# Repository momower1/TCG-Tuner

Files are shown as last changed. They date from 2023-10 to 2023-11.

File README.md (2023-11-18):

# TCG-Tuner
TCG-Tuner is the combination of an electronic playmat with an android app that detects individual cards and plays corresponding sound effects in trading card games. Each card needs to be double sleeved and an RFID tag sticker with a unique ID is placed outside of the inner sleeve. The TCG-Tuner electronic playmat has 8 RFID scanners, one for each card zone, and detects when a card is played and notifies the TCG-Tuner android app about its card ID over bluetooth. The app then plays a corresponding sound from the app storage directory. The BLE connection requires the device address, service UUID and characteristic UUID to be configured correctly in the app preferences menu. Then, when a tag ID is received, the app will look for the \"RFID.txt\" file in the app storage directory. This file contains mappings from tag ID to sound filename separated by \"->\" in each line. TCG-Tuner will then play the sound file that is referenced by the ID. All audio files needd to be placed into the storage directory. The storage directory path can be obtained from the app preferences menu.

Example RFID.txt content:
<br>``D368B20D -> OP02-01.wav``
<br>``8320DC0F -> OP03-17.wav``

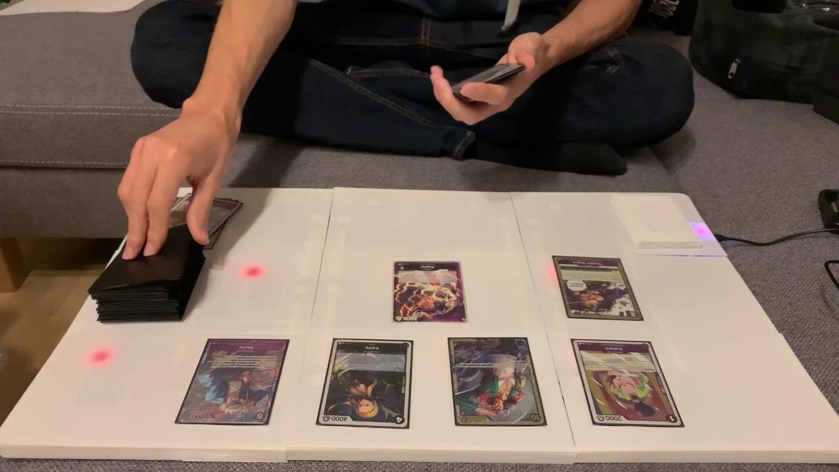
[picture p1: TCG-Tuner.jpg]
TCG-Tuner


# Hardware Setup
- Android Smartphone
- USB-Micro Power Supply
- Electronics
  - 1x ESP32-C3-MINI-1 (Development Board) https://de.aliexpress.com/item/1005004998207821.html
  - 8x RFID-RC522 Reader https://de.aliexpress.com/item/32801850680.html
  - 50x NFC Tag Sticker (NTAG215) https://www.amazon.de/dp/B0C623J1C7
  - 7x Colored Cables 24 AWG https://www.amazon.de/dp/B0B15DCC17
  - 3x Pin Header 40 Pins 2,54mm 90 Degrees https://www.ebay.de/itm/334326227743
  - 3x Pin Socket 40 Pins 2,54mm https://www.ebay.de/itm/153869572374
  - 6x Rubber Band
- 3D Printing
  - Print Settings
    - Material: PLA
    - Nozzle Size: 0.2
    - Print Temperature: 210°C
    - Bed Temperature: 60°C
    - Print Speed: 60mm/s
    - Adhesion Type: Skirt
    - Support: Off
    - Infill: 25%
  - Parts
    - 1x Bottom 1-9
    - 1x Top 1-9
    - 16x Connector
- Playmat Construction
  - 3D Print all parts
  - Bottom parts are split into 3 foldable segments consisting of 3 parts
  - The segments are connected with rubber bands, making them foldable
  - For each segment, glue the parts together using the connectors
  - Place the RFID sensors into their slots
  - Place the ESP32-C3-MINI-1 into its slot
  - Connect the pins with wires
    - For all RFID sensors
      - Solder SCK together and connect it to GPIO6 (FSPICLK)
      - Solder MOSI together and connect it to GPIO7 (FSPID)
      - Solder MISO together and connect it to GPIO2 (FSPIQ)
      - Solder RST together and connect it to GPIO10 (FSPICSO)
      - Solder GND together and connect it to GND
      - Solder 3.3V together and connect it to 3.3V
    - For each individual RFID sensor
      - Connect its SDA pin to a GPIO pin
      - E.g. One Piece TCG
        - SDA Character1 connected to GPIO0
        - SDA Character2 connected to GPIO1
        - SDA Character3 connected to GPIO3
        - SDA Character4 connected to GPIO4
        - SDA Character5 connected to GPIO5
        - SDA Event connected to GPIO9
        - SDA Leader connected to GPIO18
        - SDA Stage connected to GPIO19
  - Top parts are clipped onto the bottom parts
    - Connect the bottom segments with 3 rubber bands each and layout wires beforehand

# Software Setup
## ESP32-C3-MINI-1
- Follow instructions from https://docs.espressif.com/projects/arduino-esp32/en/latest/installing.html
  - Install Arduino IDE from https://www.arduino.cc/en/Main/Software
  - Open _Preferences_ and set _Additional Board Manager URLs_ to `https://espressif.github.io/arduino-esp32/package_esp32_index.json`
  - Open _Tools->Board->Board Manager_ and install _esp32_ platform by Espressif Systems
  - Connect ESP32-C3-MINI-1 with USB and select _ESP32C3 Dev Module_ for the COM port
- For the RFID-RC522 board
  - In Arduino IDE open _Tools->Manage Libraries_ and install _MFRC522_ by GithubCommunity
- For Dictionary data type
  - In Arduino IDE open _Tools->Manage Libraries_ and install _Dictionary_ by Anatoli Arkhipenko

## Android App
- Download Android Studio https://developer.android.com/studio
- Open the project

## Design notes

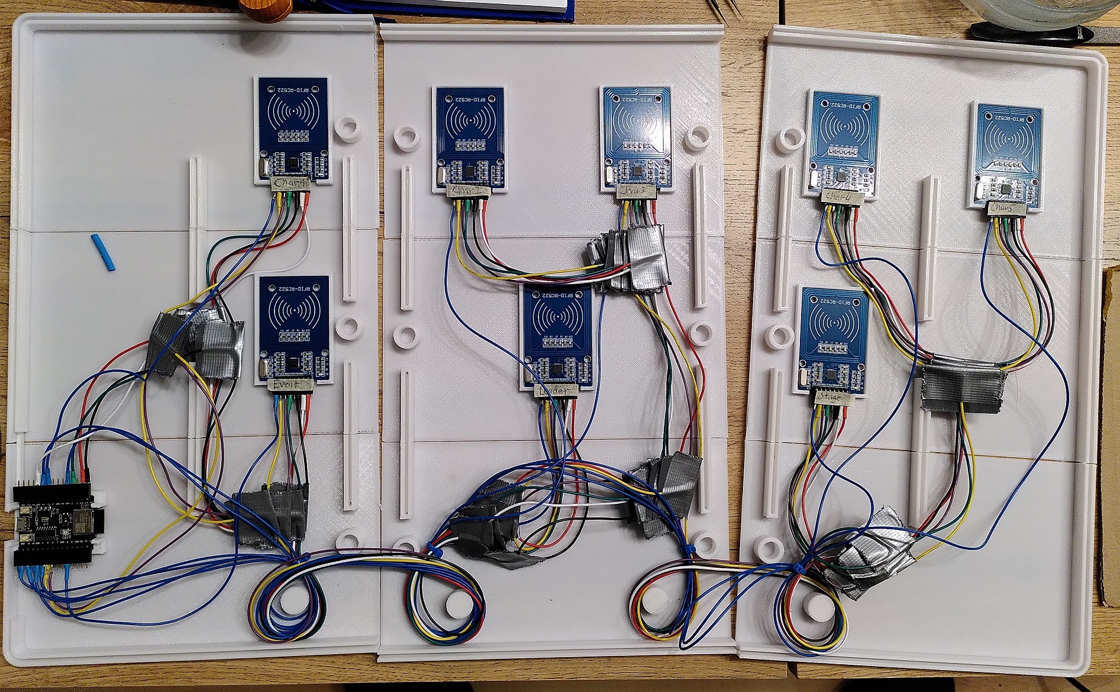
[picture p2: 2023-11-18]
Playmat Hardware.jpg

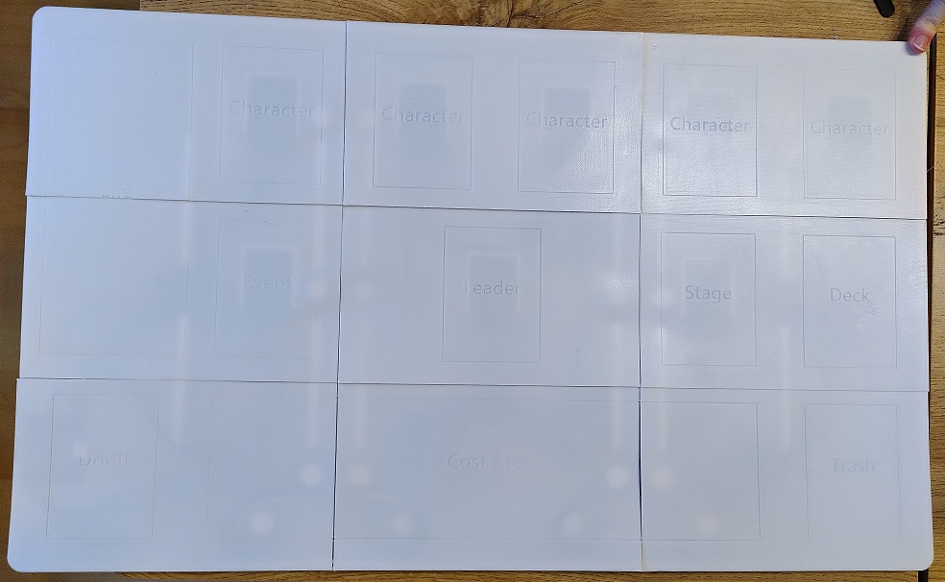
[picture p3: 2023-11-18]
Playmat.jpg

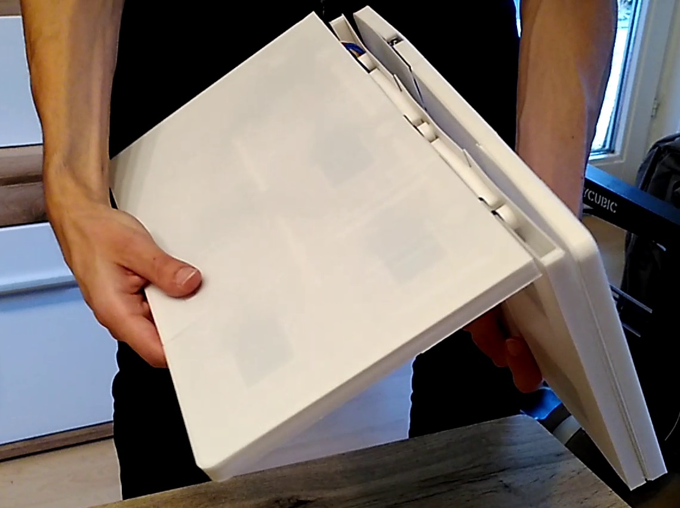
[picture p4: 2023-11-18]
Playmat Folding.jpg

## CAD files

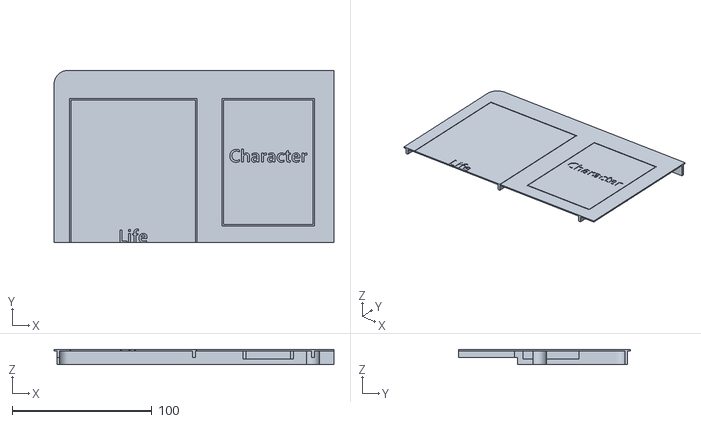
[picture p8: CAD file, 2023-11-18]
CAD/Top 3.stl
200.0 x 123.0 x 10.8

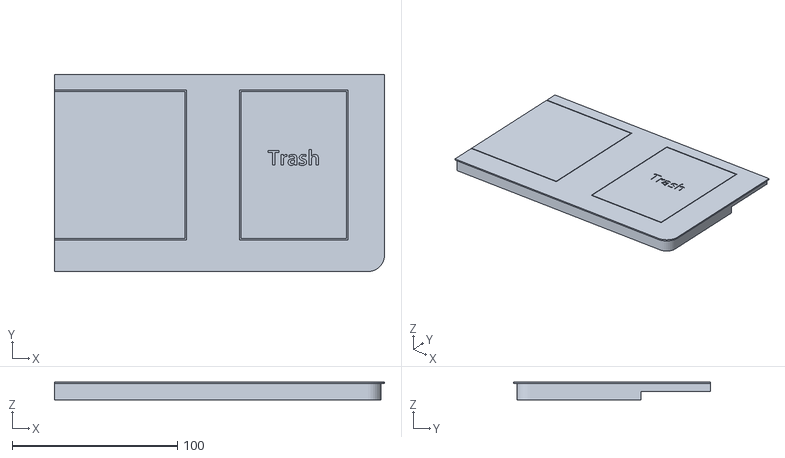
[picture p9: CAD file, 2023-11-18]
CAD/Top 9.stl
200.0 x 119.5 x 10.8

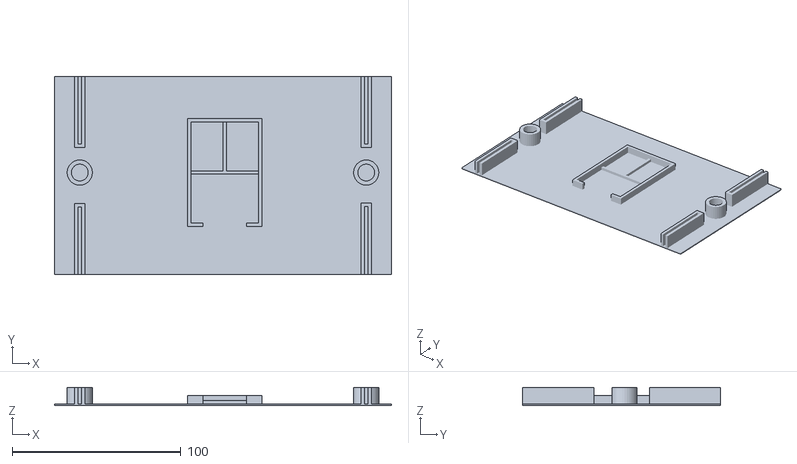
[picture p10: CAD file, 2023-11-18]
CAD/Bottom 7.stl
200.0 x 117.5 x 10.8

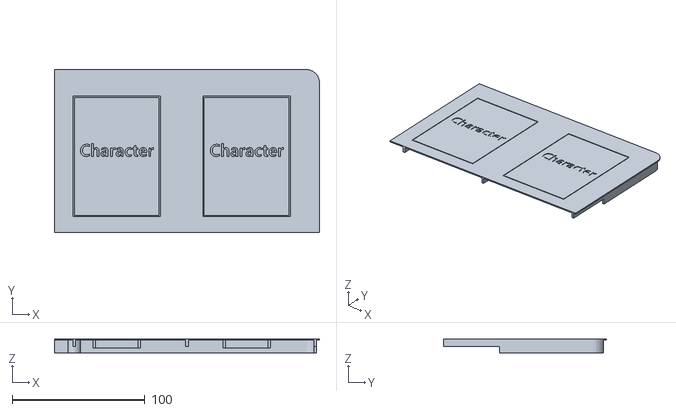
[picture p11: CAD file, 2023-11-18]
CAD/Top 1.stl
200.0 x 123.0 x 10.8

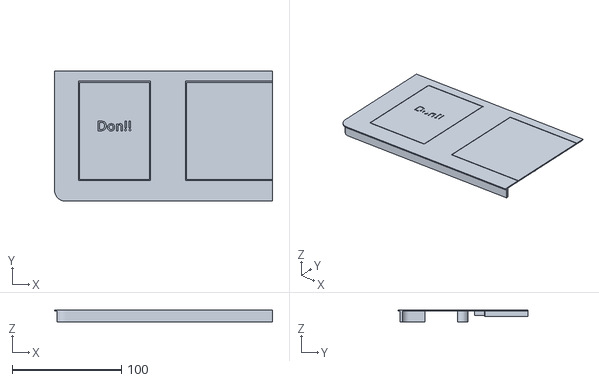
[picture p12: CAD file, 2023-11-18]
CAD/Top 2.stl
200.0 x 119.5 x 10.8

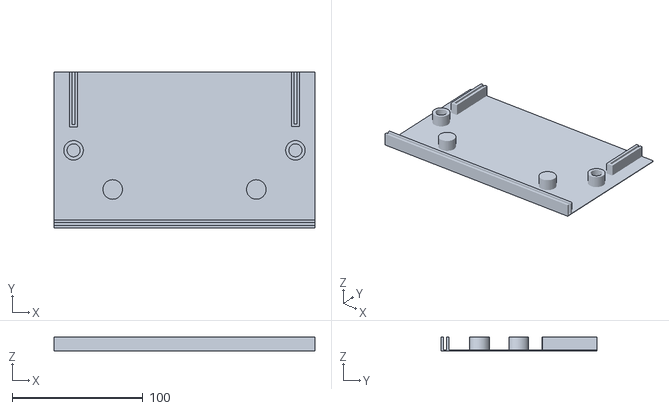
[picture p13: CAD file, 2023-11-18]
CAD/Bottom 5.stl
200.0 x 119.5 x 11.0

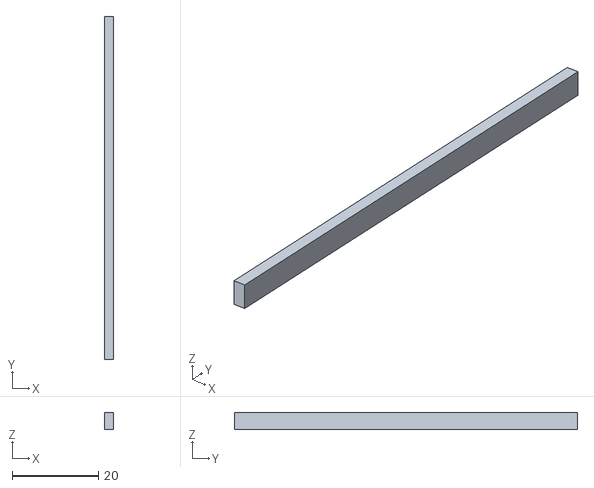
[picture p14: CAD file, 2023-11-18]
CAD/Connector.stl
2.00 x 79.6 x 4.00

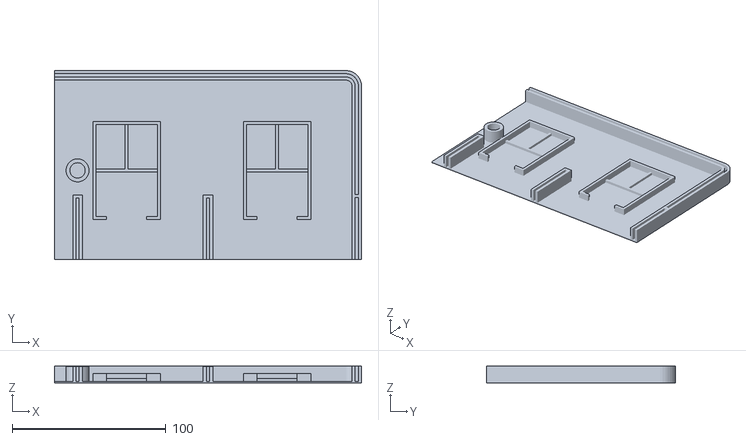
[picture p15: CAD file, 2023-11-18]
CAD/Bottom 1.stl
200.0 x 123.0 x 11.0

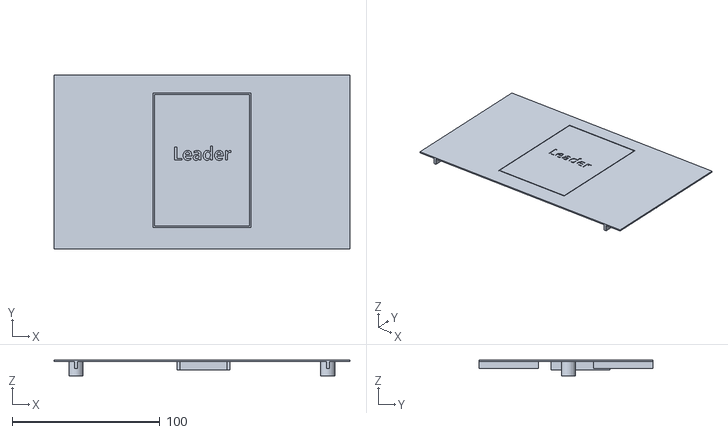
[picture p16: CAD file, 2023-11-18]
CAD/Top 7.stl
200.0 x 117.5 x 10.8

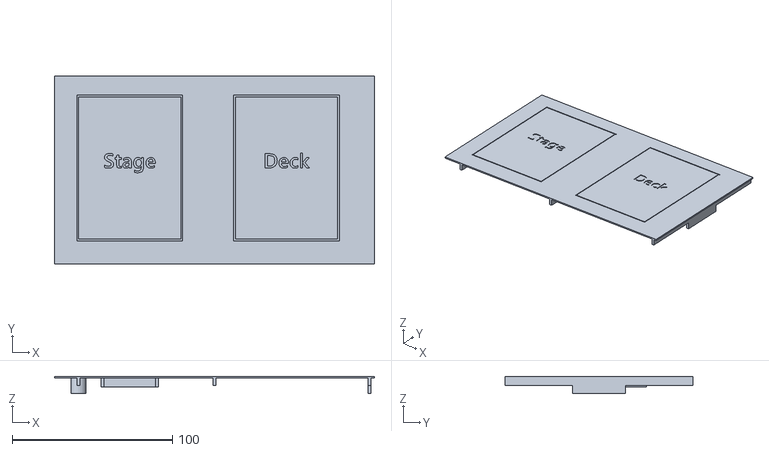
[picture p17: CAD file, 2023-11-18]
CAD/Top 8.stl
200.0 x 117.5 x 10.8

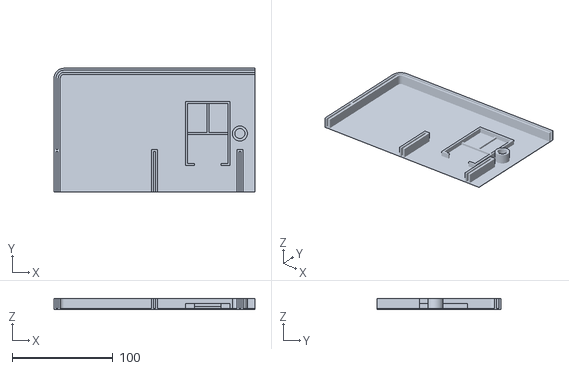
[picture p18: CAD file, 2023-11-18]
CAD/Bottom 3.stl
200.0 x 123.0 x 11.0

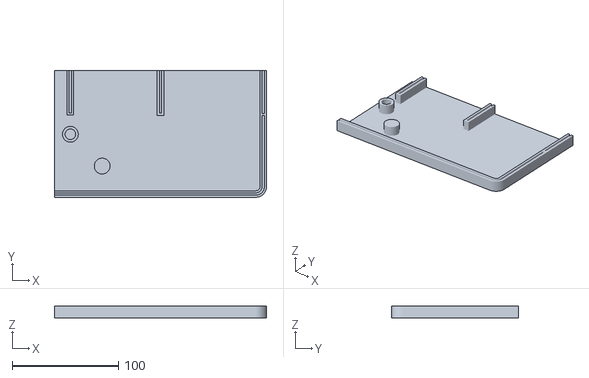
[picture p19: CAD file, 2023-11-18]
CAD/Bottom 9.stl
200.0 x 119.5 x 11.0

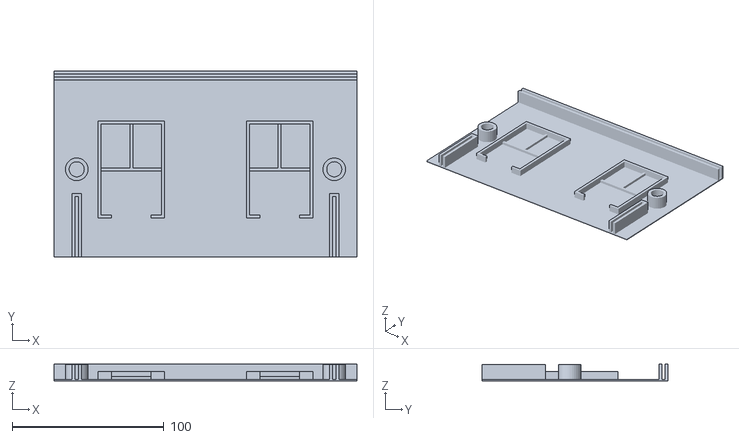
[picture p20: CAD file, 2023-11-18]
CAD/Bottom 6.stl
200.0 x 123.0 x 11.0

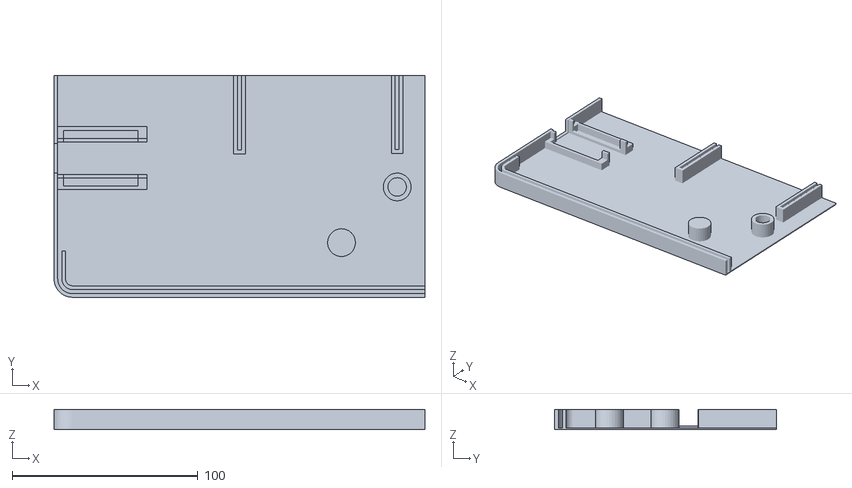
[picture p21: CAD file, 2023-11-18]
CAD/Bottom 2.stl
200.0 x 119.5 x 11.0

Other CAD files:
CAD/Top 5.stl
CAD/Bottom 8.stl
CAD/Top 6.stl
CAD/Top 4.stl
CAD/Bottom 4.stl

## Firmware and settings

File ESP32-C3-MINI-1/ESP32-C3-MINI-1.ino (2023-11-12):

#include <BLEDevice.h>
#include <BLEServer.h>
#include <BLE2902.h>
#include <SPI.h>
#include <MFRC522.h>
#include <Dictionary.h>

// https://www.uuidgenerator.net/
// Choose unique identifiers for the BLE service and characteristic
const char* uuidService = "5f804f25-4bd9-457a-ac2d-ba39563d9b66";
const char* uuidCharacteristic = "bbe3aeba-fe89-464f-9a3b-b845b758b239";

const int rfidCount = 8;
const byte rfidPinsSDA[rfidCount] = { 0, 1, 3, 4, 5, 8, 18, 19 };
const byte rfidPinRST = 10;

const byte spiPinSCK = 6;   // FSPICLK
const byte spiPinMISO = 2;  // FSPIIQ
const byte spiPinMOSI = 7;  // FSPIID

const int uidTimeout = 3000;

BLEServer* bleServer = nullptr;
BLECharacteristic* bleCharacteristic = nullptr;

Dictionary* uidToTimeMap = nullptr;

class ServerCallbacks: public BLEServerCallbacks
{
    void onConnect(BLEServer* bleServer)
    {
      Serial.println("Connected");
      bleServer->startAdvertising();
      Serial.println("Restarted advertising...");
    };

    void onDisconnect(BLEServer* bleServer)
    {
      Serial.println("Disconnected");
      bleServer->startAdvertising();
      Serial.println("Restarted advertising...");
    }
};

BLE2902 ble2902;
ServerCallbacks serverCallbacks;

MFRC522 rfids[rfidCount];

void setup()
{
  Serial.begin(115200);

  // RFID-RC522
  SPI.begin(spiPinSCK, spiPinMISO, spiPinMOSI, -1);

  for (int rfidIndex = 0; rfidIndex < rfidCount; rfidIndex++)
  {
    rfids[rfidIndex].PCD_Init(rfidPinsSDA[rfidIndex], rfidPinRST);
  }

  pinMode(rfidPinRST, OUTPUT);
  digitalWrite(rfidPinRST, LOW);

  BLEDevice::init("ESP32-C3-MINI-1");

  // Create the BLE Server
  bleServer = BLEDevice::createServer();
  bleServer->setCallbacks(&serverCallbacks);

  // Create the BLE Service
  BLEService *bleService = bleServer->createService(uuidService);

  // Create a BLE Characteristic
  bleCharacteristic = bleService->createCharacteristic(uuidCharacteristic, BLECharacteristic::PROPERTY_READ | BLECharacteristic::PROPERTY_NOTIFY);
  bleCharacteristic->addDescriptor(&ble2902);

  // Start the service
  bleService->start();

  // Start advertising (automatically stops once a client connects)
  BLEAdvertising *bleAdvertising = BLEDevice::getAdvertising();
  bleAdvertising->addServiceUUID(uuidService);
  bleAdvertising->setScanResponse(false);
  bleAdvertising->setMinPreferred(0);
  BLEDevice::startAdvertising();

  Serial.println("Started advertising...");

  uidToTimeMap = new Dictionary();
}

void loop()
{
  for (int rfidIndex = 0; rfidIndex < rfidCount; rfidIndex++)
  {
    digitalWrite(rfidPinRST, HIGH);
    rfids[rfidIndex].PCD_Init();

    // Waiting a bit is necessary to reliably detect Mifare Ultralight tags
    delay(1);

    if (rfids[rfidIndex].PICC_IsNewCardPresent())
    {
      if (rfids[rfidIndex].PICC_ReadCardSerial())
      {
        String uidString = "";

        for (int i = 0; i < rfids[rfidIndex].uid.size; i++)
        {
          if (rfids[rfidIndex].uid.uidByte[i] <= 0xF)
          {
            uidString += "0";
          }
          
          uidString += String(rfids[rfidIndex].uid.uidByte[i], HEX);
        }

        uidString.toUpperCase();

        // Check if the uid has already been detected recently
        if (uidToTimeMap->search(uidString).length() == 0)
        {
          // BLE Notify
          if (bleServer->getConnectedCount() > 0)
          {
            bleCharacteristic->setValue((uint8_t*)rfids[rfidIndex].uid.uidByte, rfids[rfidIndex].uid.size);
            bleCharacteristic->notify();
            Serial.println("BLE Notify");
          }
        }

        uidToTimeMap->insert(uidString, String(millis()));

        Serial.println(uidString);

        rfids[rfidIndex].PICC_HaltA();
        rfids[rfidIndex].PCD_StopCrypto1();
      }
    }

    digitalWrite(rfidPinRST, LOW);
  }

  // Remove uids that have timed out since they have not been detected recently
  // Only remove one id at a time since the dictionary indices are recreated after every remove
  String keyToRemove = "";
  size_t uidToTimeMapCount = uidToTimeMap->count();

  for (int i = 0; i < uidToTimeMapCount; i++)
  {
    unsigned long uidTime = uidToTimeMap->value(i).toInt();

    if ((millis() - uidTime) > uidTimeout)
    {
      keyToRemove = uidToTimeMap->key(i);
      break;
    }
  }

  if (keyToRemove.length() > 0)
  {
    uidToTimeMap->remove(keyToRemove);
  }
}

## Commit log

2023-10-15 Added RFID-522 sensor reading
2023-10-17 Added support for multiple readers (only SDA pin is connected individually)
2023-10-22 Connecting to BLE devices, permissions not working correctly
    Right now need to go to settings for the app and enable permissions (otherwise the app crashes)
2023-10-22 Removed no longer required sample gatt attributes class
2023-10-22 Creating a more simple android app without complicated device discovery and UI
2023-10-24 Added preferences button
2023-10-26 Fixed issue with detecting Mifare Ultralight tags
    [ESP32-C3-MINI-1.ino]
2023-10-26 Added info button
2023-11-11 Using all 8 RFID sensors but seems like GPIO 9 does not work
    [ESP32-C3-MINI-1.ino]
2023-11-12 Using GPIO 8 instead of 9 fixes issue
    [ESP32-C3-MINI-1.ino]
2023-11-18 Added CAD design files
    [Bottom 1.stl, Bottom 2.stl, Bottom 3.stl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]
